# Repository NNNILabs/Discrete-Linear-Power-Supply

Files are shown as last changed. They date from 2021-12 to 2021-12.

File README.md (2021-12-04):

# Discrete Linear Power Supply
Fully discrete dual tracking linear supply with CC and CV

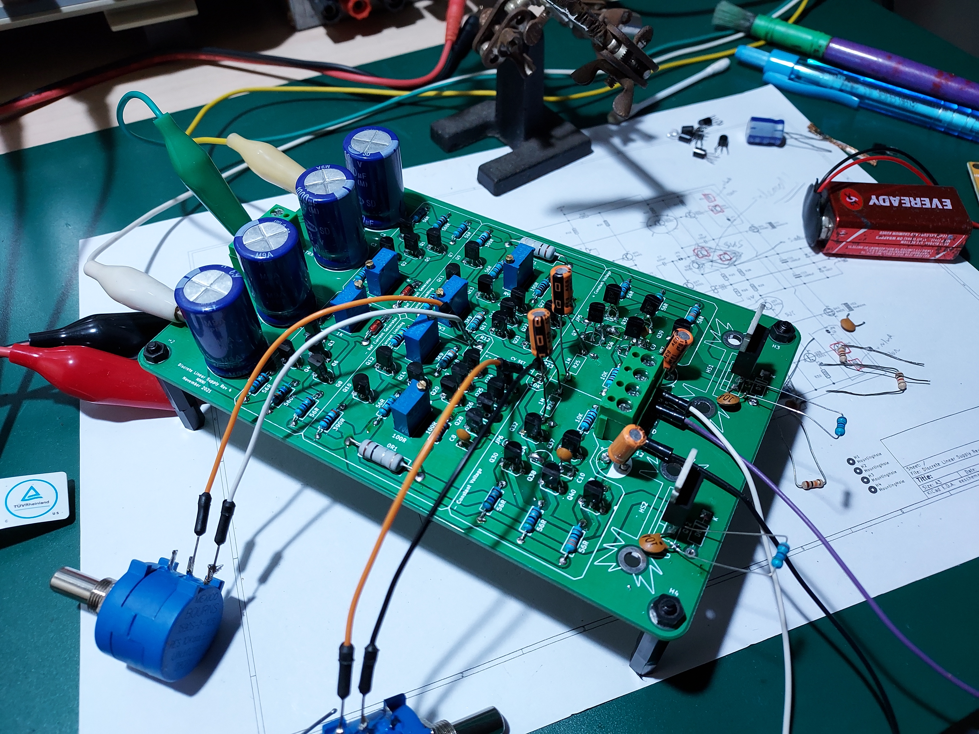
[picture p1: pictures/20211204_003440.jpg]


## Why?
I was not fully satsified with my previous linear supply based on op-amps, so I decided that I was done with the "black box" approach and decided to go fully discrete this time. 

## How?
The linear supply consists of three parts - the reference, the constant voltage circuit and the constant current circuit. The positive and negative parts are more or less mirror images of each other. 

### The References
The reference element here is a zener diode. The circuit does not operate using reference voltages, but rather reference currents supplied by degenerated PNP/NPN current sources/sinks. 
The Zener diode sets the voltage across the emitter resistors of the buffer transistors, forming current sources/sinks. This current is mirrored and fed back into the Zener diodes, creating a stable closed-loop reference. 

### The Current Limiting Circuitry
The current limiting circuitry is a mix of at least three different circuit ideas from various sources - the emitter input differential amplifier from The Art of Electronics: The X Chapters, the ZDS1009 IC, and the current comparator from Designing Analog Chips. The easiest explanantion is that a constant voltage is set across the left degeneration resistor of the mirror ladder, and when the shunt exceeds this voltage, the output transistor is turned on, pulling the output MOSFET low till the current setpoint is reached. The limit threshold is set by a constant current through the set potentiometer, the voltage across which is mirrored on a resistor which sets the current through the degeneration resistor, the voltage across whic determines the shunt voltage threshold.

### The Voltage Regulating Circuitry 
Again an example of emitter input differential amplifiers - the circuit tries to make the emitter voltages the same and drives the output MOSFET accordingly. The voltage is set by a constant current through the set potentiometer. 

### Notes
- Dual tracking is achieved by sinking/sourcing the same current through the set potentiometers, which creates a voltage across it based on the resistance. Since the current source outputs would otherwise be "floating" (i.e., the voltage across the shunt is constant but there is no guarantee as to where it is relative to ground), two 1M balance resistors connected to ground are added. 
- The value of the compensation resistor and capacitor between the gate and drain of each MOSFET depends on the particular MOSFET type - experiment with different R and C values to get the best compensation, in my case 100nF and 56 Ohms barely worked. 

## Should I make one?
It's up to you - I created this mostly as a challenge but with the hopes of being able to use it - but it was not to be - another "Look, ma! No ICs" circuit bending victim. 
- Oscillations on the output
- Pathetic power supply rejection
- Output voltage drifts randomly

## Conclusion
Some interesting circuit ideas, if you want to pick something up.

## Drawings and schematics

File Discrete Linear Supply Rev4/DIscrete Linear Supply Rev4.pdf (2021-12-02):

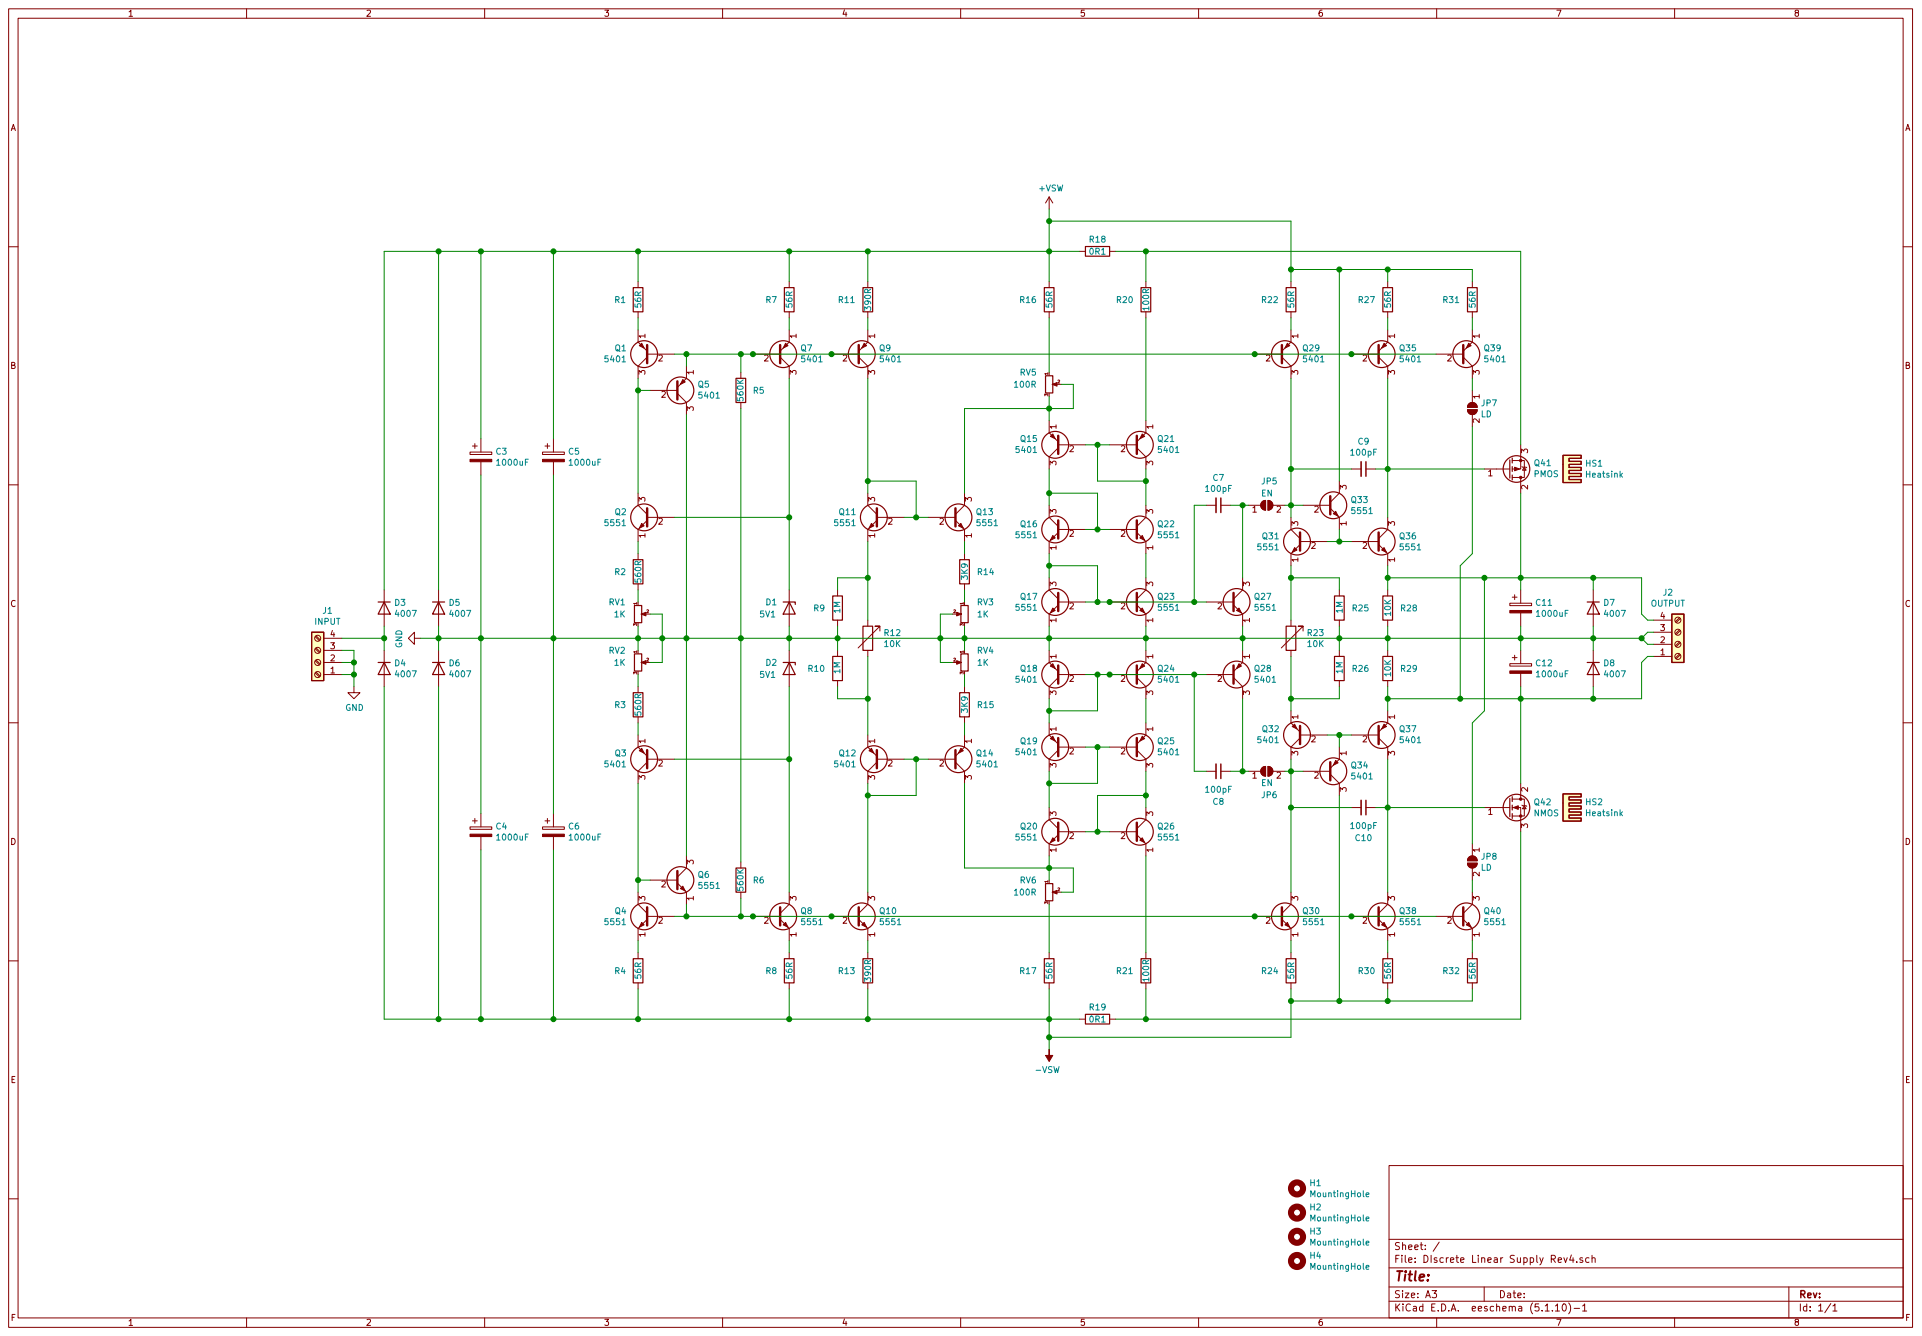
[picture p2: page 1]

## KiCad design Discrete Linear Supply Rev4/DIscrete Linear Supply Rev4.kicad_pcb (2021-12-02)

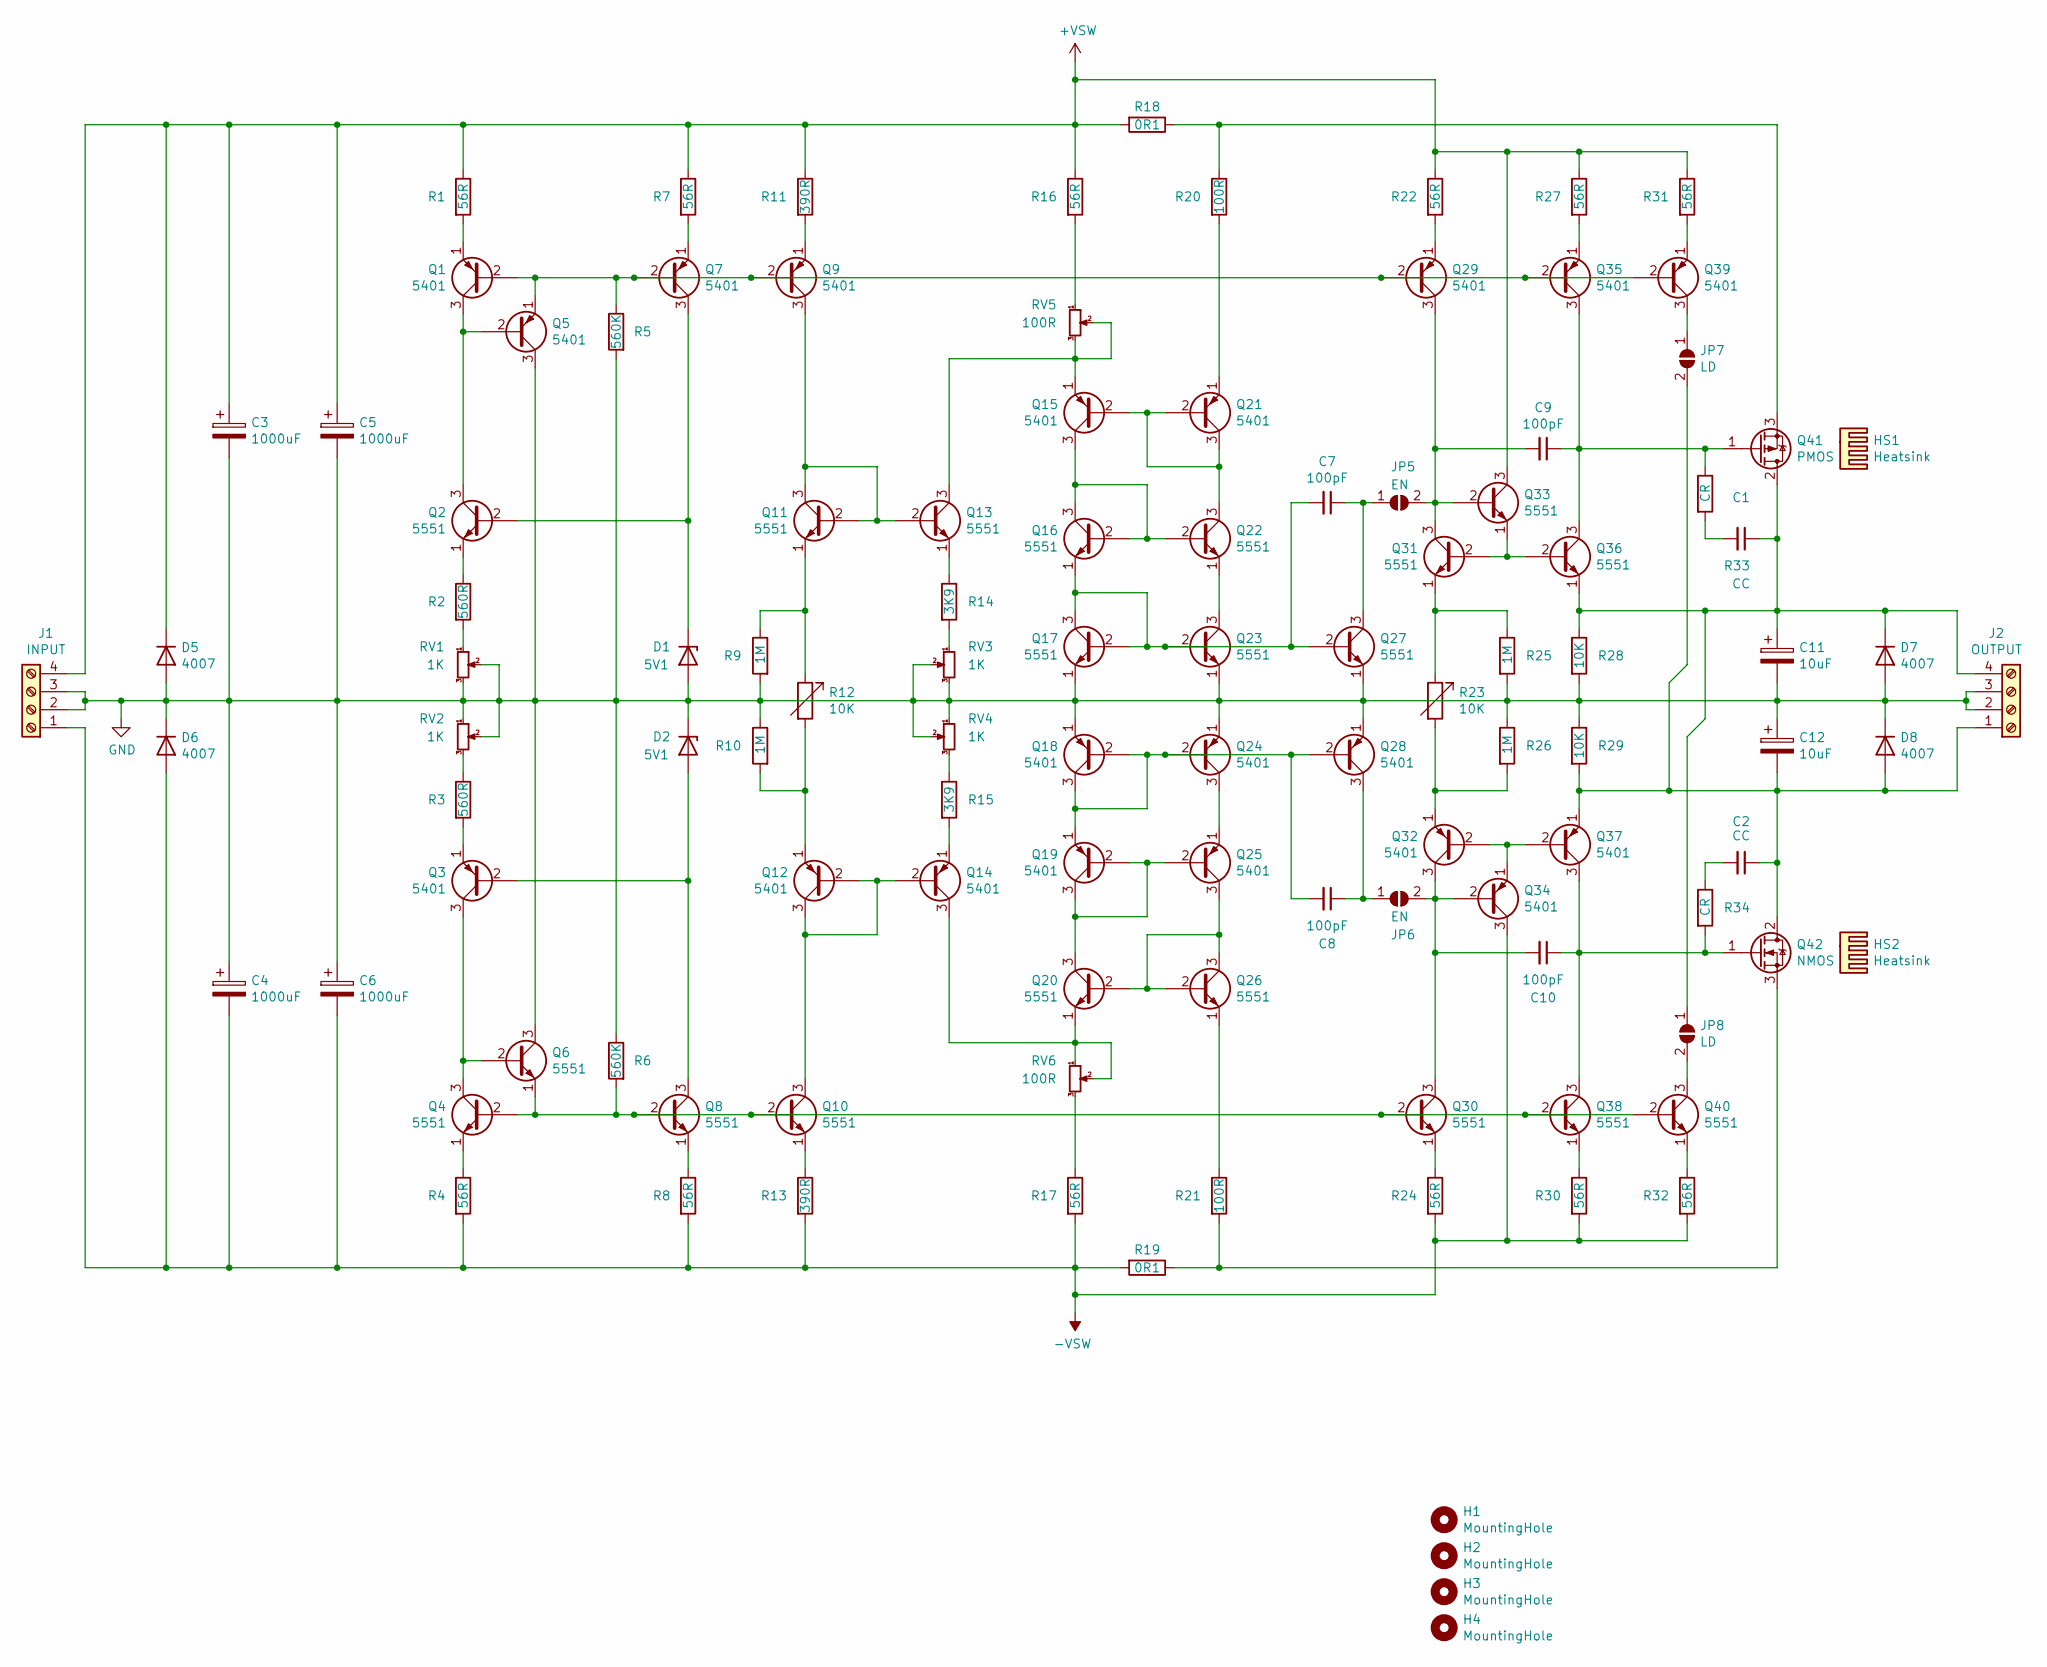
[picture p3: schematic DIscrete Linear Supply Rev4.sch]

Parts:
C1, C2: CC; C_Disc_D3.8mm_W2.6mm_P2.50mm
C3, C4, C5, C6: 1000uF; CP_Radial_D16.0mm_P7.50mm
C7, C8, C9, C10: 100pF; C_Disc_D3.8mm_W2.6mm_P2.50mm
C11, C12: 10uF; CP_Radial_D8.0mm_P5.00mm
D1, D2: 5V1; D_DO-41_SOD81_P10.16mm_Horizontal
D5, D6, D7, D8: 4007; D_DO-41_SOD81_P10.16mm_Horizontal
H1, H2, H3, H4: MountingHole; MountingHole_3.2mm_M3_Pad_Via
HS1, HS2: Heatsink; Heatsink_Fischer_SK104-STCB_35x13mm__2xDrill3.5mm_ScrewM3
J1: INPUT; TerminalBlock_bornier-4_P5.08mm
J2: OUTPUT; TerminalBlock_bornier-4_P5.08mm
JP5, JP6: EN; SolderJumper-2_P1.3mm_Open_RoundedPad1.0x1.5mm
JP7, JP8: LD; SolderJumper-2_P1.3mm_Open_RoundedPad1.0x1.5mm
Q1, Q3, Q5, Q7, Q9, Q12, Q14, Q15, Q18, Q19, Q21, Q24, Q25, Q28, Q29, Q32, Q34, Q35, Q37, Q39: 5401; TO-92L_Inline_Wide
Q2, Q4, Q6, Q8, Q10, Q11, Q13, Q16, Q17, Q20, Q22, Q23, Q26, Q27, Q30, Q31, Q33, Q36, Q38, Q40: 5551; TO-92L_Inline_Wide
Q41: PMOS; TO-220-3_Vertical
Q42: NMOS; TO-220-3_Vertical
R1, R4, R7, R8, R16, R17, R22, R24, R27, R30, R31, R32: 56R; R_Axial_DIN0207_L6.3mm_D2.5mm_P10.16mm_Horizontal
R2, R3: 560R; R_Axial_DIN0207_L6.3mm_D2.5mm_P10.16mm_Horizontal
R5, R6: 560K; R_Axial_DIN0207_L6.3mm_D2.5mm_P10.16mm_Horizontal
R9, R10, R25, R26: 1M; R_Axial_DIN0207_L6.3mm_D2.5mm_P10.16mm_Horizontal
R11, R13: 390R; R_Axial_DIN0207_L6.3mm_D2.5mm_P10.16mm_Horizontal
R12, R23: 10K; PinHeader_1x02_P2.54mm_Vertical
R14, R15: 3K9; R_Axial_DIN0207_L6.3mm_D2.5mm_P10.16mm_Horizontal
R18, R19: 0R1; R_Axial_DIN0414_L11.9mm_D4.5mm_P20.32mm_Horizontal
R20, R21: 100R; R_Axial_DIN0207_L6.3mm_D2.5mm_P10.16mm_Horizontal
R28, R29: 10K; R_Axial_DIN0207_L6.3mm_D2.5mm_P10.16mm_Horizontal
R33, R34: CR; R_Axial_DIN0207_L6.3mm_D2.5mm_P10.16mm_Horizontal
RV1, RV2, RV3, RV4: 1K; Potentiometer_Bourns_3296W_Vertical
RV5, RV6: 100R; Potentiometer_Bourns_3296W_Vertical

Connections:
unnamed: C1.2, R33.2
unnamed: C2.2, R34.1
unnamed: C7.1, JP5.1 (A), Q27.3 (C)
unnamed: C7.2, Q16.1 (E), Q17.2 (B), Q17.3 (C), Q23.2 (B), Q27.2 (B)
unnamed: C8.1, JP6.1 (A), Q28.3 (C)
unnamed: C8.2, Q18.2 (B), Q18.3 (C), Q19.1 (E), Q24.2 (B), Q28.2 (B)
unnamed: C9.1, Q35.3 (C), Q36.3 (C), Q41.1 (G), R33.1
unnamed: C9.2, JP5.2 (B), Q29.3 (C), Q31.3 (C), Q33.2 (B)
unnamed: C10.1, Q37.3 (C), Q38.3 (C), Q42.1 (G), R34.2
unnamed: C10.2, JP6.2 (B), Q30.3 (C), Q32.3 (C), Q34.2 (B)
unnamed: C1.1, C11.1, D7.1 (K), J2.4, JP8.1 (A), Q36.1 (E), Q41.2 (D), R28.1
unnamed: C2.1, C12.2, D8.2 (A), J2.1, JP7.2 (B), Q37.1 (E), Q42.2 (D), R29.2
unnamed: D1.1 (K), Q2.2 (B), Q7.3 (C)
unnamed: D2.2 (A), Q3.2 (B), Q8.3 (C)
unnamed: JP7.1 (A), Q39.3 (C)
unnamed: JP8.2 (B), Q40.3 (C)
unnamed: Q1.1 (E), R1.2
unnamed: Q1.2 (B), Q5.1 (E), Q7.2 (B), Q9.2 (B), Q29.2 (B), Q35.2 (B), Q39.2 (B), R5.1
unnamed: Q1.3 (C), Q2.3 (C), Q5.2 (B)
unnamed: Q2.1 (E), R2.1
unnamed: Q3.1 (E), R3.2
unnamed: Q3.3 (C), Q4.3 (C), Q6.2 (B)
unnamed: Q4.1 (E), R4.1
unnamed: Q7.1 (E), R7.2
unnamed: Q8.1 (E), R8.1
unnamed: Q9.1 (E), R11.2
unnamed: Q10.1 (E), R13.1
unnamed: Q4.2 (B), Q6.1 (E), Q8.2 (B), Q10.2 (B), Q30.2 (B), Q38.2 (B), Q40.2 (B), R6.2
unnamed: Q10.3 (C), Q12.2 (B), Q12.3 (C), Q14.2 (B)
unnamed: Q11.1 (E), R9.1, R12.1
unnamed: Q9.3 (C), Q11.2 (B), Q11.3 (C), Q13.2 (B)
unnamed: Q12.1 (E), R10.2, R12.2
unnamed: Q13.1 (E), R14.1
unnamed: Q13.3 (C), Q15.1 (E), RV5.2, RV5.3
unnamed: Q14.1 (E), R15.2
unnamed: Q14.3 (C), Q20.1 (E), RV6.1, RV6.2
unnamed: Q15.2 (B), Q21.2 (B), Q21.3 (C), Q22.3 (C)
unnamed: Q15.3 (C), Q16.2 (B), Q16.3 (C), Q22.2 (B)
unnamed: Q19.2 (B), Q19.3 (C), Q20.3 (C), Q25.2 (B)
unnamed: Q20.2 (B), Q25.3 (C), Q26.2 (B), Q26.3 (C)
unnamed: Q21.1 (E), R20.2
unnamed: Q22.1 (E), Q23.3 (C)
unnamed: Q24.3 (C), Q25.1 (E)
unnamed: Q26.1 (E), R21.1
unnamed: Q29.1 (E), R22.2
unnamed: Q30.1 (E), R24.1
unnamed: Q31.1 (E), R23.1, R25.1
unnamed: Q31.2 (B), Q33.1 (E), Q36.2 (B)
unnamed: Q32.1 (E), R23.2, R26.2
unnamed: Q32.2 (B), Q34.1 (E), Q37.2 (B)
unnamed: Q35.1 (E), R27.2
unnamed: Q38.1 (E), R30.1
unnamed: Q39.1 (E), R31.2
unnamed: Q40.1 (E), R32.1
unnamed: Q41.3 (S), R18.1, R20.1
unnamed: Q42.3 (S), R19.1, R21.2
unnamed: R2.2, RV1.1
unnamed: R3.1, RV2.3
unnamed: R14.2, RV3.1
unnamed: R15.1, RV4.3
unnamed: R16.2, RV5.1
unnamed: R17.1, RV6.3

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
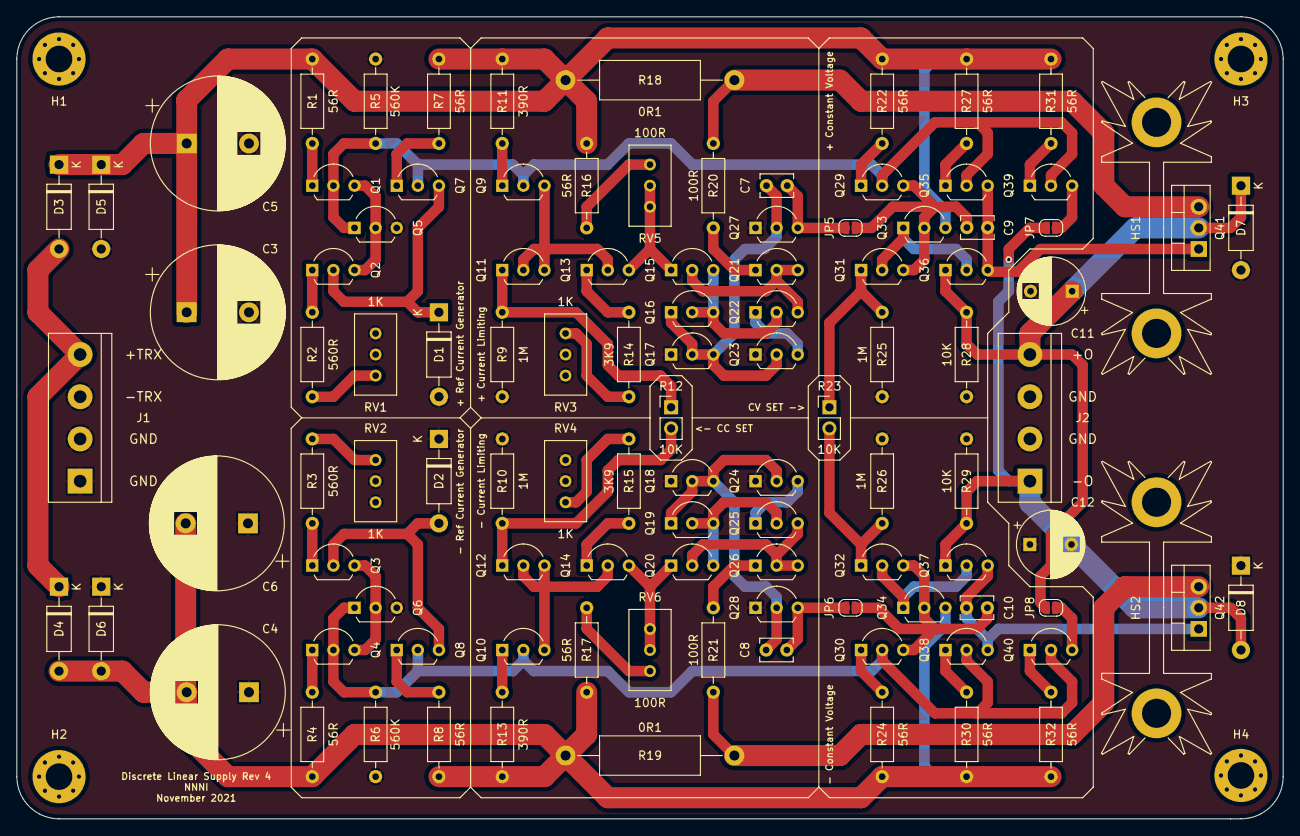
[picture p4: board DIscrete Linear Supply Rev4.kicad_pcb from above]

Board: 2 copper layers, 152.4 x 96.5 mm, 110 parts (0 on the bottom side), 64 nets.

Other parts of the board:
D3, D4: 4007; D_DO-41_SOD81_P10.16mm_Horizontal

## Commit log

2021-12-02 hardware files, compensation not added yet
    [DIscrete Linear Supply Rev4-B_Cu.gbr, DIscrete Linear Supply Rev4-B_Mask.gbr, DIscrete Linear Supply Rev4-B_Paste.gbr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]
2021-12-04 schematics up-to-date
    [DIscrete Linear Supply Rev4-B_Cu.gbr, DIscrete Linear Supply Rev4-B_Mask.gbr, DIscrete Linear Supply Rev4-B_Paste.gbr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]
